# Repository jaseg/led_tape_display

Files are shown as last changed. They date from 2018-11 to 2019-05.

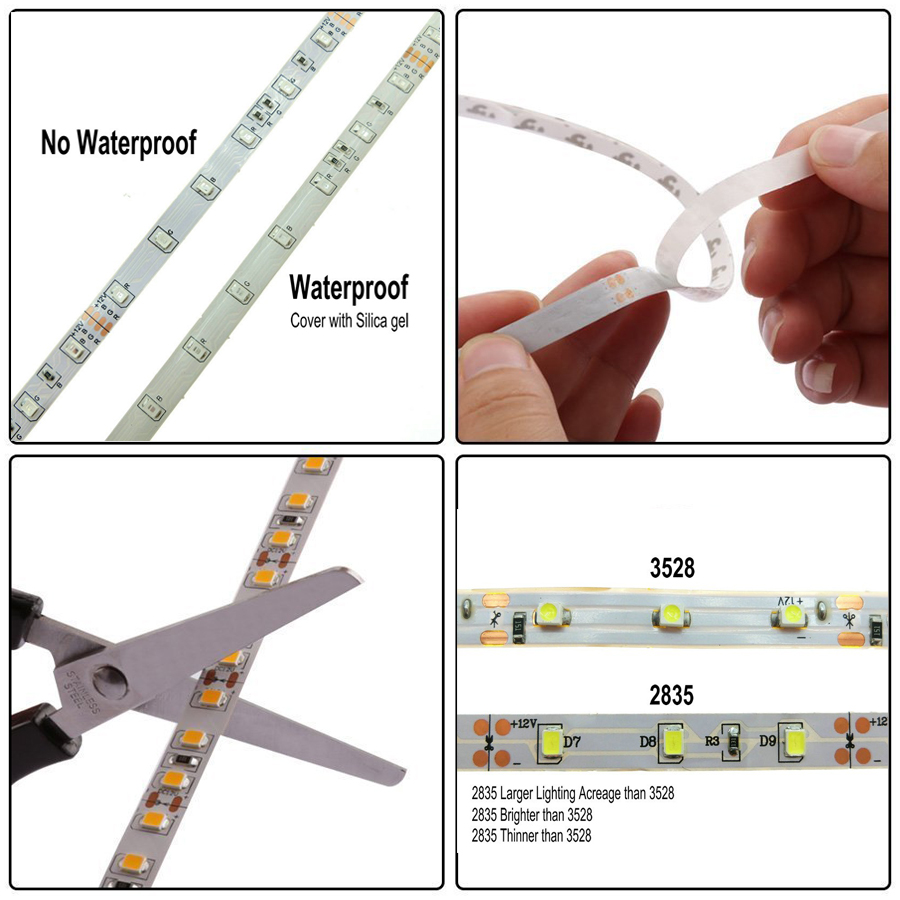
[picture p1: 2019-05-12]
driver/led_tape.png

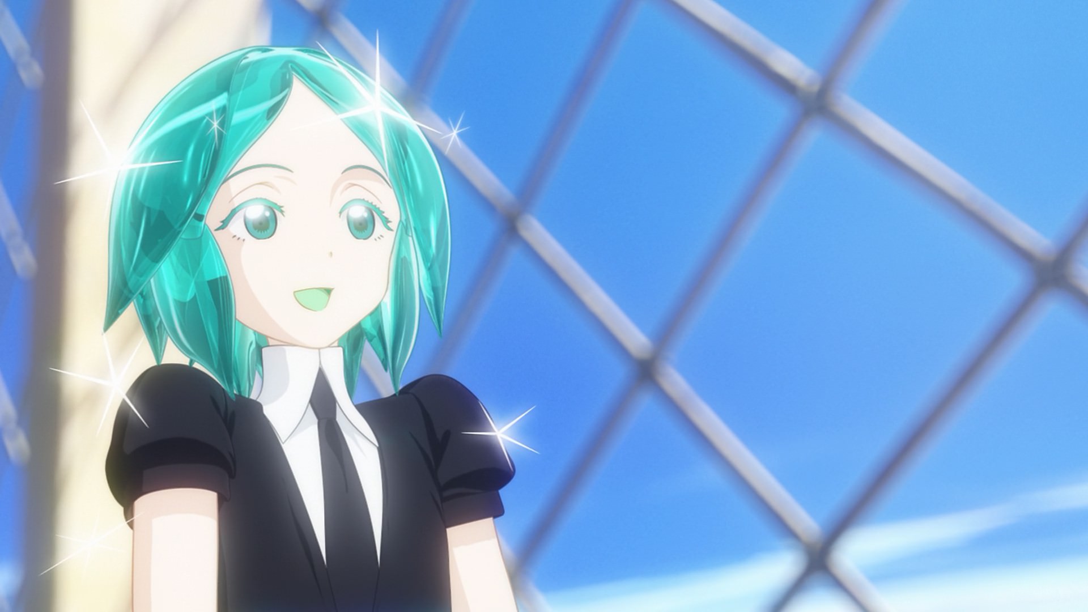
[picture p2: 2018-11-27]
center/phos.jpg

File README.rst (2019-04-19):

LED-tape based segment display
==============================

This is a work-in-progress repository containing hard- and software source files for an 8-segment LED display based on
cheap single-color LED tape. The display consists of one digit driver per display digit that receive power and
transceive data through a two-wire powerline bus. This bus can support 10-50 digits depending on the size of the display
(and thus current consumption). The bus is driven by a driver board that is in turn controlled through RS-485.

The hardware is mostly finalized and can be found in ``center`` (digit controller) and ``driver`` (bus driver). The
firmware is still WIP and can be found in ``center_fw`` (digit controller), ``driver_fw`` (bus driver) and
``common`` (common 8b10b implementation).

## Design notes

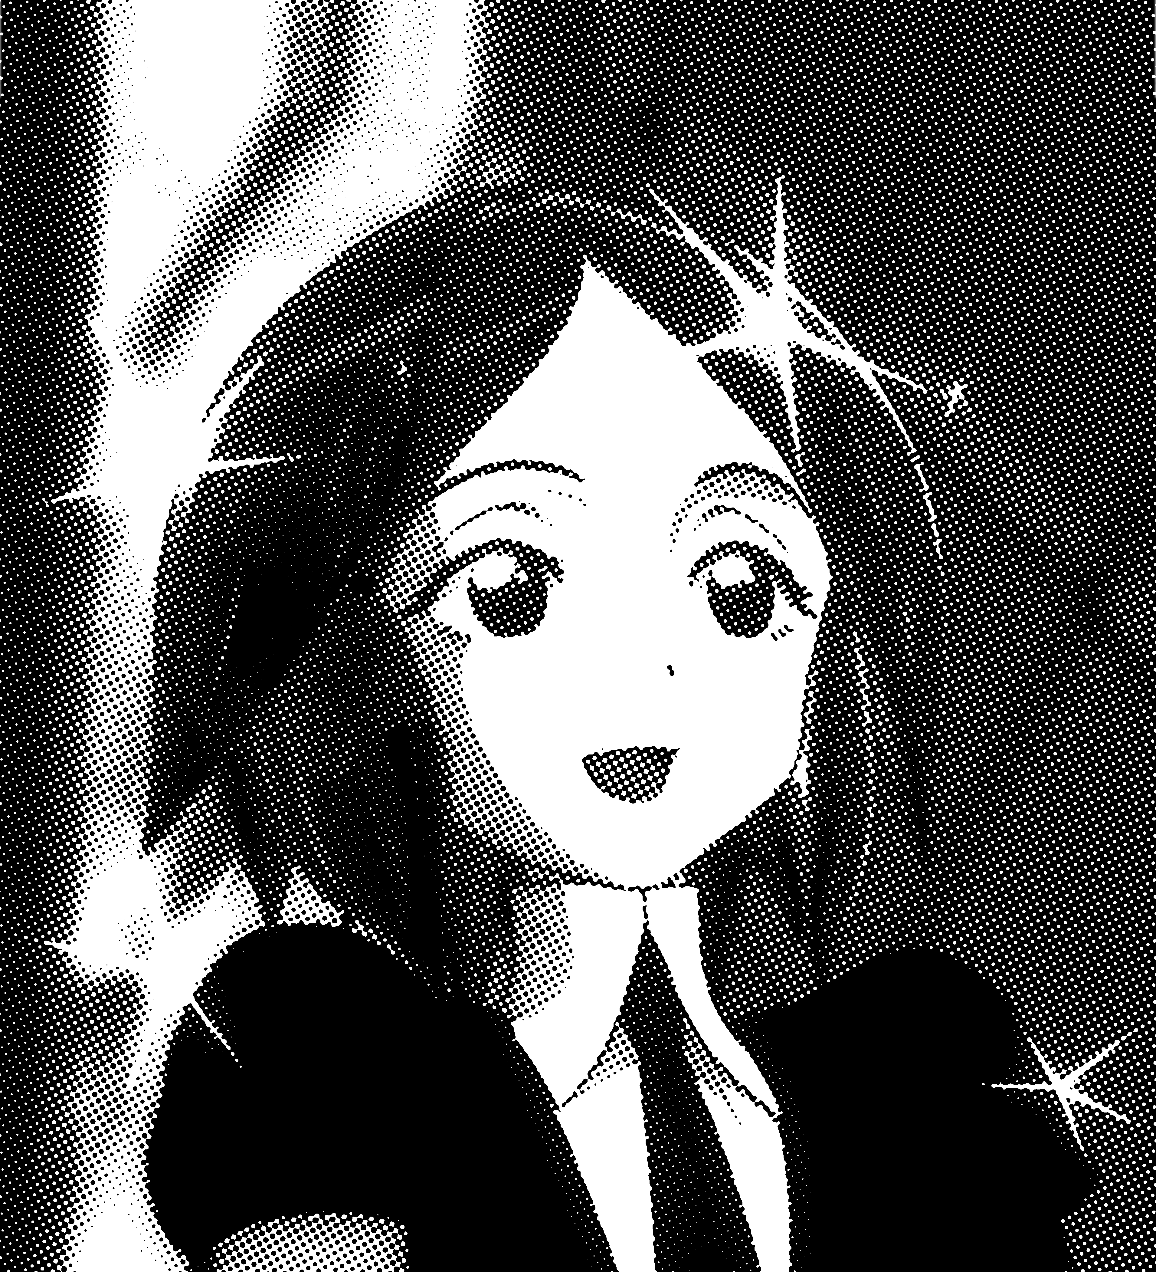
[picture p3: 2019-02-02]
center/tape_center_overlay.png

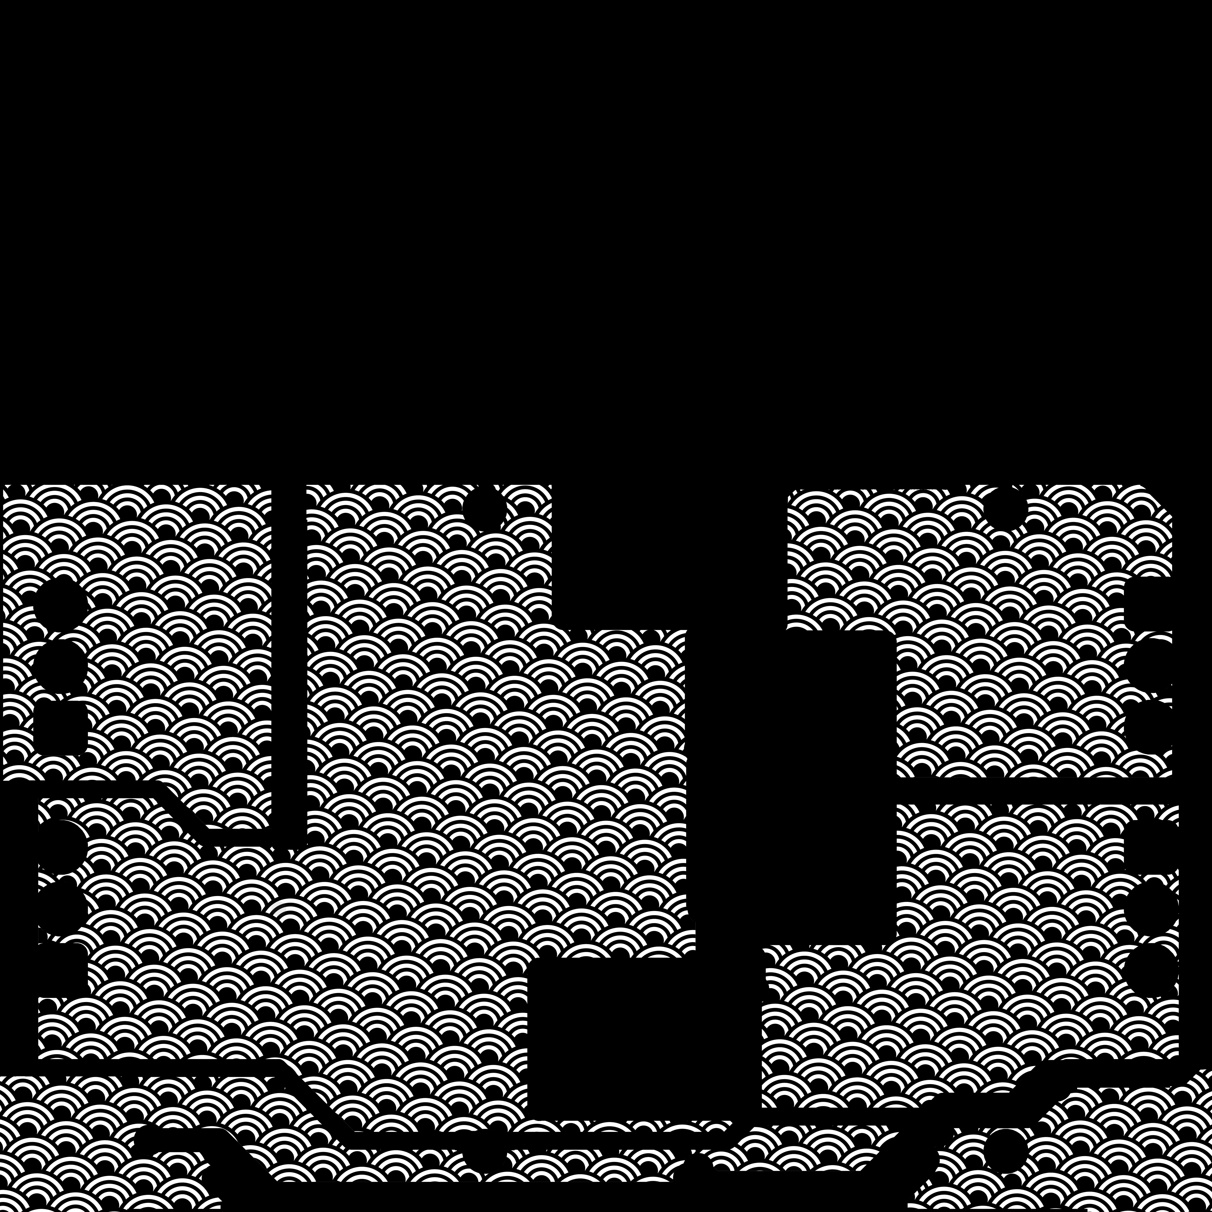
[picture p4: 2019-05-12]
driver/8seg_drv_bottom_mask_overlay_coarse.png

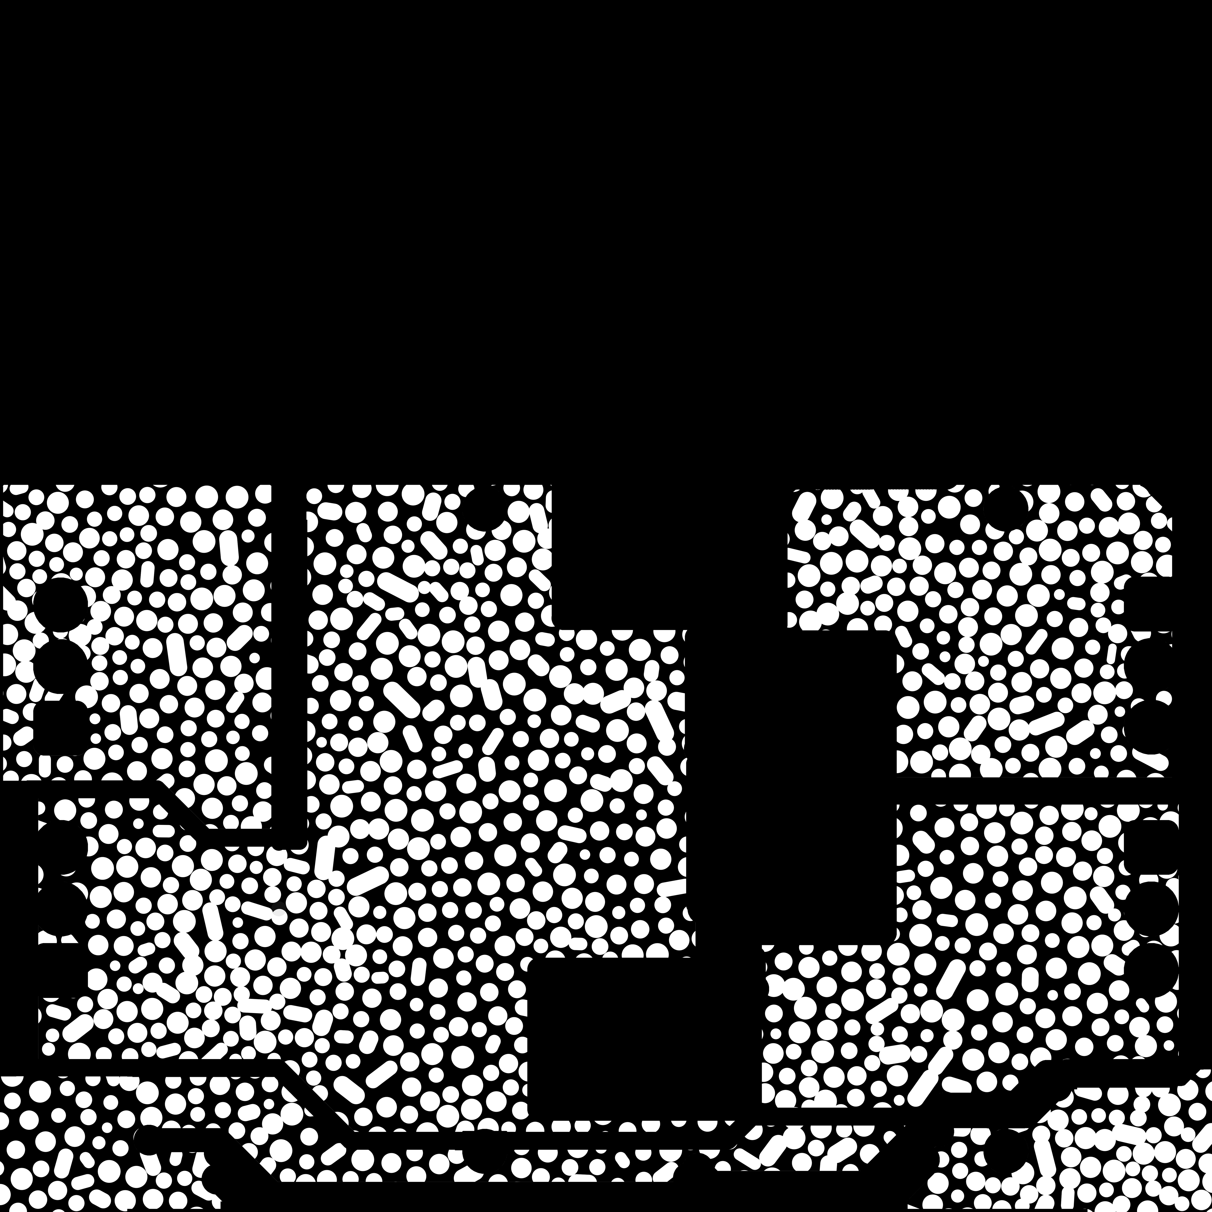
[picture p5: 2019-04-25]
driver/8seg_drv_bottom_mask_overlay.png

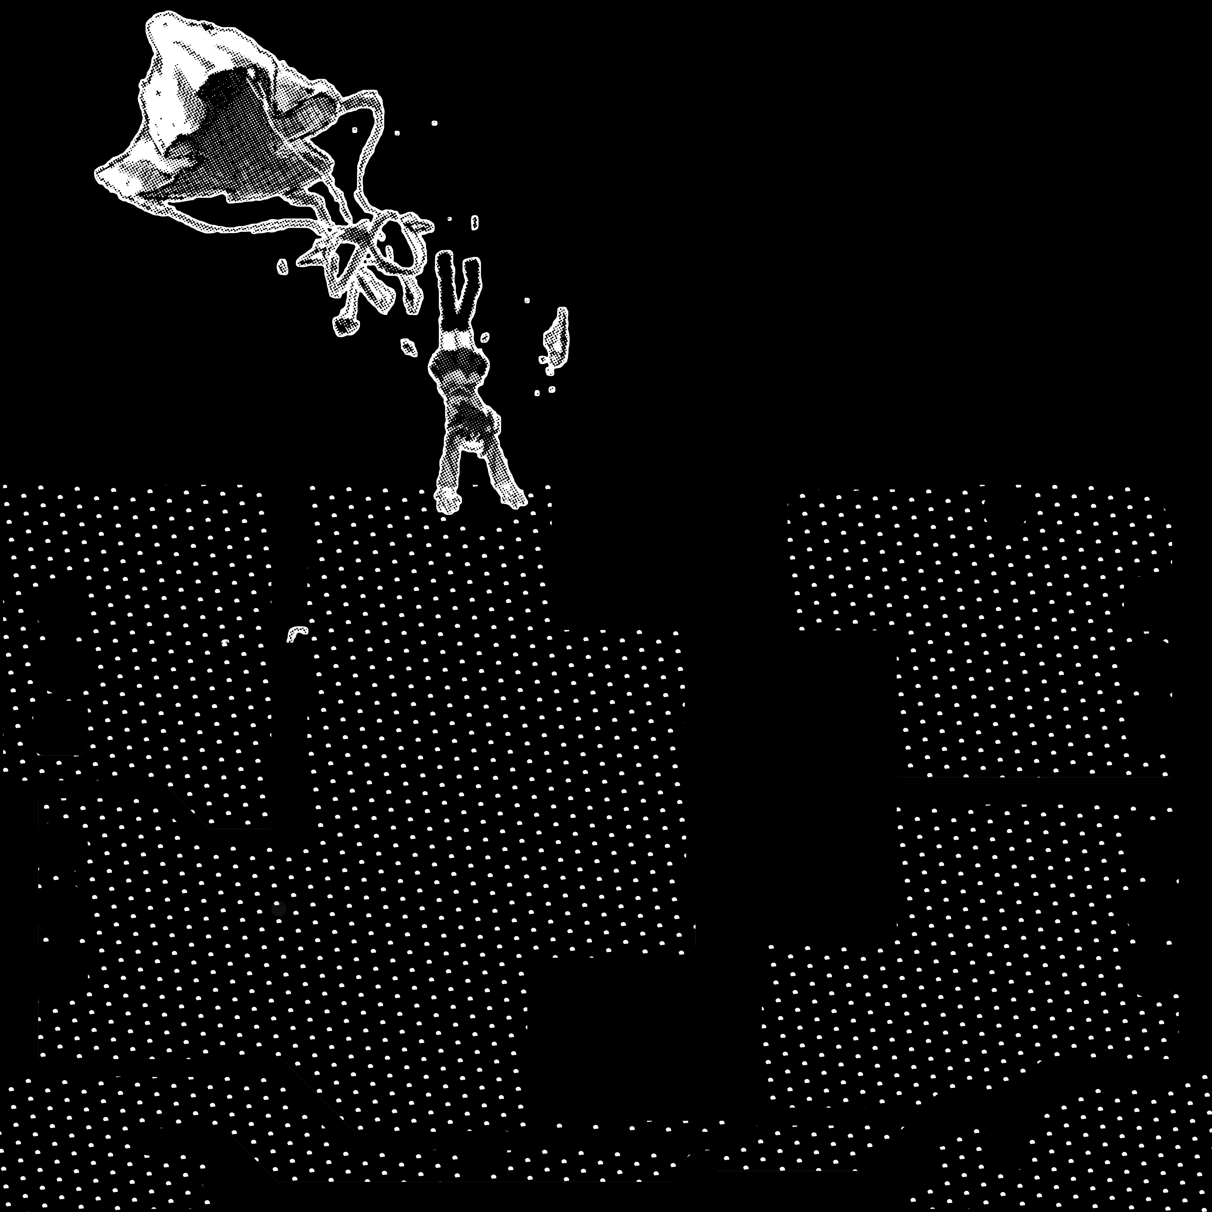
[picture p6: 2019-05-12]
driver/8seg_drv_bottom_silk_overlay.png

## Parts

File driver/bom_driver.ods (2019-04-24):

8seg Driver
Refs | # | Val | Pkg | Mfg | Source | P/N | JPY MOQ Price | USD MOQ Price | MOQ | URL
J1 | 1 | OUT_A OUT_B IN_VCC IN_GND | 3P P5.08 |  | LCSC |  |  | 1.46 | 5 | https://www.aliexpress.com/item/5PCS-PCB-Screw-Terminal-Blocks-Conenctor-2-54-3-5-3-81-5-0-5-08/32956034619.html
 | 1 | 1602 I2C LCD w/ backlight |  |  | Ali |  |  | 1.88 | 1 | https://www.aliexpress.com/item/1602-LCD-Module-Blue-Yellow-Green-Screen-with-IIC-I2C-16x2-LCD-Backlight-Module-LCD-1602/32891917063.html
R29 R30 R31 R32 R28 | 5 | 5mR 1W | 2512 |  | LCSC |  |  | 3.85 | 50 | https://www.aliexpress.com/item/50PCS-2512-SMD-Resistor-1-alloy-resistor-2W-0-005R-0-005-ohm-5mR-R005/32848255551.html
U1 | 1 | MT3608 | SOT23-6 |  | LCSC |  |  | 0.8 | 10 | https://www.aliexpress.com/item/10PCS-Special-chip-for-mobile-power-MT3608-B6286-SOT23-6-5V-1-2A/32838336209.html
U4 U5 | 2 | TC4427 | SOIC8 |  | LCSC |  |  | 2.76 | 10 | https://www.aliexpress.com/item/10PCS-TC4427ACOA-SOP-8-TC4427-SOP-TC4427AEOA-TC4427A-MOSFET-driver-new-original/32869458552.html
U7 | 1 | INA226 | MSOP10 P0.5 |  | LCSC |  |  | 2.2 | 1 | https://www.aliexpress.com/item/INA226AIDGS-INA226AIDGSR-INA226AIDGST-INA226/32822237180.html
U8 | 1 | MCP9804_SOIC | SOIC8 |  | LCSC |  | 282 |  | 1 | https://www.marutsu.co.jp/pc/i/27045774/
C10 | 1 | 22u | D5P2 |  | LCSC |  | 59 |  | 1 | https://www.marutsu.co.jp/pc/i/13867268/
J9 | 1 | SWD | Angled header 1x4 100mil |  | Stock |  | 48 |  | 10 | https://www.marutsu.co.jp/pc/i/59243/
L1 | 1 | 10u | NR50xx | Taiyo-Yuden | LCSC |  | 0.76 | 0.45 | 1 | https://www.marutsu.co.jp/GoodsDetail.jsp?q=%20NR5040T100M%20&salesGoodsCode=15561626&shopNo=3
Q1 Q2 Q3 Q4 | 4 | TPHR6503PL | SOP Advance |  | LCSC |  | 298 | 1.82 | 1 | https://www.digikey.com/product-detail/en/toshiba-semiconductor-and-storage/TPHR6503PLL1Q/TPHR6503PLL1QCT-ND/6099957
R1, R7 | 1 | 10R .5W | 1206 |  | LCSC |  | 5 |  | 1 | https://www.marutsu.co.jp/pc/i/857080/#
U6 | 1 | STM32F103C8Tx | LQFP48 P0.5 |  | Ali |  |  | 1.14 | 1 | https://www.aliexpress.com/item/CS32F103C8T6-Completely-replace-STM32F103C8T6-STM32F103-LQFP-48-In-Stock-ARM-based-32-bit-MCU-with-Flash/32952782064.html
U2 | 1 | AMS1117-5.0 | SOT223 |  | LCSC
U3 | 1 | AMS1117-3.3 | SOT223 |  | Stock
C15 | 1 | 100u | D10P5 |  | Stock
C16 C17 | 2 | 1u | 0603 |  | LCSC
C1 C18 C4 C9 | 4 | 10u | 0603 |  | Stock
C19 C2 C3 | 3 | 470u | D10P5 |  | Stock
C20 C22 | 2 | 12p | 0603 |  | Stock
C11 C12 C13 C14 C21 C23 C24 C29 C5 | 9 | 100n | 0603 |  | Stock
D1 | 1 | 2A schottky | SMB |  | Stock
U10 U9 | 2 | PC817 | DIP-4 |  | Stock
Y1 | 1 | 8MHz | 3225 |  | Stock
D2 D3 D4 D5 | 4 | cyan | 2835 |  | Stock
D6 D7 D8 D9 | 4 | pink | 2835 |  | Stock
J3 | 1 | UART_DEBUG | 1x4 100mil straight |  | Stock
J4 | 1 | USB_B_Micro |  |  | Stock
J5 | 1 | CH340E module | 1x6 straight high/female |  | Stock
J6 | 1 | LCD connector | XH2.54 4pin |  | Stock
R11 R12 R13 R14 R15 R16 R17 R18 | 8 | 150 | 0603 |  | Stock
R19 R20 R21 R22 | 4 | 0R | 0603 |  | Stock
R2 | 1 | 100k | 0603 |  | Stock
R23 R26 R27 R37 R38 | 5 | 1k5 | 0603 |  | Stock
R24 R25 | 2 | 22 | 0603 |  | Stock
R3 R8 | 2 | 47k | 0603 |  | Stock
R33 R35 | 2 | 390 | 0603 |  | Stock
R34 | 1 | 720 | 0603 |  | Stock
R39 | 1 | 680 | 0603 |  | Stock
R4 | 1 | 3k3 | 0603 |  | Stock
R10 R36 R5 R9 | 4 | 10k | 0603 |  | Stock
SW1 SW2 | 2 | SW_Push | 6mm switch |  | Stock

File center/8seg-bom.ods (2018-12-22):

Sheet: Sheet1
8seg
Number of devices: |  | 20
Description | Available? | Package | Mfg | MPN | Supplier | Supplier PN | Qty | MOQ | Unit | Price/MOQ | Price/ Unit | Price base | Price total | MOQ match | Price total MOQ | Excl | TempSum | MOQ delta cost | MOQ delta qty | URL
uC STM32 | stock | TSSOP-20 | ST | STM32F030F4P6 | Ali |  | 1 | 50 | Pcs | $20.900 | $0.418 | $0.418 | $8.360 | 50 | $20.900 |  | $20.900 | $12.540 | 30 | https://www.aliexpress.com/item/Free-shipping-50pcs-lots-STM32F030F4P6-STM32F030-MCU-ARM-16K-FLASH-20TSSOP-best-quality/32281734555.html
Voltage regulator 3.3V | stock | SOT-223 |  | AP1117-33 | Ali |  | 2 | 100 | Pcs | $1.770 | $0.018 | $0.035 | $0.708 | 100 | $1.770 |  | $1.770 | $1.062 | 60 | https://www.aliexpress.com/item/Free-Shipping-One-Lot-100pcs-AMS1117-3-3V-AMS1117-1117-3-3V-1A-Voltage-Regulator-LDO/2040294608.html
Schottky diode | ordered | SMB |  | SS510 | Ali |  | 4 | 100 | Pcs | $2.780 | $0.028 | $0.111 | $2.224 | 100 | $2.780 |  | $2.780 | $0.556 | 20 | https://www.aliexpress.com/item/100pcs-lot-Diode-SS510-SMB-SCHOTTKY-DIODE-5A-100V/32763626070.html
C 1000u 25V | ordered | D10/P5.0 |  |  | Ali |  | 1 | 50 | Pcs | $3.660 | $0.073 | $0.073 | $1.464 | 50 | $3.660 |  | $3.660 | $2.196 | 30 | https://www.aliexpress.com/item/CNIKESIN-50PCS-25V1000UF-new-genuine-high-quality-power-supply-line-super-electrolytic-capacitor-1000UF-25V-10X17mm/3281012004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
C 470uF 10V | ordered | D10/P5.0 |  |  | Ali |  | 1 | 30 | Pcs | $1.380 | $0.046 | $0.046 | $0.920 | 30 | $1.380 |  | $1.380 | $0.460 | 10 | https://www.aliexpress.com/item/25V-470UF-8-12-aluminum-electrolytic-capacitor-470uf-25v/32814887162.html
C 0603 10u/6.3V X7R | ordered | 0603 | Samsung | CL10A106MQ8NNNC | LCSC |  | 1 | 50 | Pcs |  | $0.014 | $0.014 | $0.272 | 50 | $0.680 |  | $0.680 | $0.408 | 30 | https://lcsc.com/product-detail/Multilayer-Ceramic-Capacitors-MLCC-SMD-SMT_SAMSUNG_CL10A106MQ8NNNC_10uF-106-20-6-3V_C1691.html
C 0603 10u/25V X7R | ordered | 0603 | Murata | GRM188R61E106MA73D | LCSC |  | 1 | 50 | Pcs |  | $0.118 | $0.118 | $0.000 | 50 | $5.875 | 1 | $0.000 | $0.000 | 30 | https://lcsc.com/product-detail/Multilayer-Ceramic-Capacitors-MLCC-SMD-SMT_MuRata_GRM188R61E106MA73D_10uF-106-20-25V_C91606.html
C 0603 100n | stock | 0603 | Huaxin | 0603B104M250 | LCSC |  | 2 | 50 | Pcs |  | $0.009 | $0.017 | $0.340 | 50 | $0.425 |  | $0.425 | $0.085 | 10 | https://lcsc.com/product-detail/Multilayer-Ceramic-Capacitors-MLCC-SMD-SMT_100nF-104-20-25V_C107569.html
R 10k 1% | stock | 0603 | Ralec | RTT031002FTP | LCSC |  | 4 | 100 | Pcs |  | $0.002 | $0.008 | $0.152 | 100 | $0.190 |  | $0.190 | $0.038 | 20 | https://lcsc.com/product-detail/Chip-Resistor-Surface-Mount_10KR-1002-1_C103199.html
R 3k3 1% | stock | 0603 | Ralec | RTT033302FTP | LCSC |  | 2 | 100 | Pcs |  | $0.005 | $0.010 | $0.200 | 100 | $0.500 |  | $0.500 | $0.300 | 60 | https://lcsc.com/product-detail/Chip-Resistor-Surface-Mount_33KR-3302-1_C103544.html
Schottky diode | ordered | MiniMELF | Semtech | LL60P-D4004 | LCSC |  | 2 | 100 | Pcs |  | $0.029 | $0.058 | $1.168 | 100 | $2.920 |  | $2.920 | $1.752 | 60 | https://lcsc.com/product-detail/Schottky-Barrier-Diodes-SBD_STLL60P_C51724.html
MOSFET P-ch | stock | SOT-23 | Various | AO3401 | Ali |  | 2 | 100 | Pcs | $1.770 | $0.018 | $0.040 | $0.796 | 100 | $1.990 |  | $1.990 | $1.194 | 60 | https://www.aliexpress.com/item/100pcs-lot-free-shipping-MOS-AO3401-AO3401A19T-SOT-23-100-new-Original-Quality-Assurance/2030993203.html
Zener diode 8.2V | ordered | MiniMELF |  |  | Ali |  | 2 | 200 | Pcs | $0.980 | $0.005 | $0.010 | $0.196 | 200 | $0.980 |  | $0.980 | $0.784 | 160 | https://www.aliexpress.com/item/1-2W-Zener-diode-ZMM-0-5W-2V0-2V2-2V4-2V7-3V0-3V3-3V6-3V9-4V3/32829966736.html
Crystal 8MHz | ordered | 3225 |  |  | Ali |  | 1 | 10 | Pcs | $1.470 | $0.147 | $0.147 | $0.000 | 20 | $2.940 | 1 | $0.000 | $0.000 | 0 | https://www.aliexpress.com/item/10pcs-3-2x2-5-3225-12-16-25-24-26-40-20-8-27-32MHZ-passive/32954531147.html
C 12p | ordered | 0603 | Huaxin | 0603N120G500CT | LCSC |  | 2 | 50 | Pcs |  | $0.010 | $0.020 | $0.404 | 50 | $0.505 |  | $0.505 | $0.101 | 10 | https://lcsc.com/product-detail/Multilayer-Ceramic-Capacitors-MLCC-SMD-SMT_Huaxin-S-T-0603N120G500CT_C302050.html
Male header 1*4P | ordered | P2.54 |  |  | LCSC |  | 1 | 20 | Pcs |  | $0.019 | $0.019 | $0.376 | 20 | $0.376 |  | $0.376 | $0.000 | 0 | https://lcsc.com/product-detail/Male-Header_2-54mm-1-4P-HeaderG-FRegular_C152150.html
MOSFET N-ch | stock | SOT-23 | Various | AO3400 | Ali |  | 3 | 100 | Pcs | $1.990 | $0.020 | $0.060 | $1.194 | 100 | $1.990 |  | $1.990 | $0.796 | 40 | https://www.aliexpress.com/item/Free-shipping-20pcs-SMD-mosfet-transistor-SOT-23-AO3400/32360580221.html
R 620 2W | ordered | 2512 | Ralec | RTT25621JTE | LCSC |  | 1 | 50 | Pcs |  | $0.014 | $0.014 | $0.288 | 50 | $0.720 |  | $0.720 | $0.432 | 30 | https://lcsc.com/product-detail/Chip-Resistor-Surface-Mount_620R-621-5_C159179.html
PCB 58*64mm center | ordered |  |  |  | JLCPCB |  | 1 | 50 | Pcs | $18.160 | $0.363 | $0.363 | $7.264 | 50 | $18.160 |  | $18.160 | $10.896 | 30
PCB 50*50mm corner | ordered |  |  |  | JLCPCB |  | 4 | 10 | Pcs | $2.000 | $0.200 | $0.800 | $16.000 | 80 | $16.000 |  | $16.000 | $0.000 | 0
LED tape pink | ordered |  |  |  | Ali |  | 8.6 | 5 | m | $1.820 | $0.364 | $3.130 | $62.608 | 175 | $63.700 |  | $63.700 | $1.092 | 3 | https://www.aliexpress.com/item/2835-LED-Strip-Light-DC12V-IP30-not-waterproof-IP65-waterproof-SMD-3528-LED-Diode-Flexible-Tape/32881123416.html
 |  |  |  |  |  |  |  |  |  |  | Total | $5.511 | $104.934 |  |  | Total | $139.626 | $34.692
Notes:

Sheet: center
U2 | STM32F030F4P6 | Housings_SSOP:TSSOP-20_4.4x6.5mm_Pitch0.65mm | http://www.st.com/st-web-ui/static/active/en/resource/technical/document/datasheet/DM00088500.pdf
U1 | AP1117-33 | TO_SOT_Packages_SMD:SOT-223-3Lead_TabPin2 | http://www.diodes.com/datasheets/AP1117.pdf
J1 | top left | footprints:led_tape_3528_2835 | ~
J2 | top right | footprints:led_tape_3528_2835 | ~
J3 | bottom right | footprints:led_tape_3528_2835 | ~
J4 | bottom left | footprints:led_tape_3528_2835 | ~
D1 | SS510 | Diodes_SMD:D_SMB_Handsoldering | ~
D3 | SS510 | Diodes_SMD:D_SMB_Handsoldering | ~
D2 | SS510 | Diodes_SMD:D_SMB_Handsoldering | ~
D4 | SS510 | Diodes_SMD:D_SMB_Handsoldering | ~
C1 | 1000uF | Capacitor_THT:CP_Radial_D10.0mm_P5.00mm | ~
C4 | 470uF | Capacitor_THT:CP_Radial_D10.0mm_P5.00mm | ~
C2 | 10u | Capacitors_SMD:C_0603_HandSoldering | ~
C3 | 100n | Capacitors_SMD:C_0603_HandSoldering | ~
C5 | 10u | Capacitors_SMD:C_0603_HandSoldering | ~
C6 | 100n | Capacitors_SMD:C_0603_HandSoldering | ~
R1 | 10k | Resistors_SMD:R_0603_HandSoldering | ~
R2 | 10k | Resistors_SMD:R_0603_HandSoldering | ~
R4 | 3k3 | Resistors_SMD:R_0603_HandSoldering | ~
R3 | 3k3 | Resistors_SMD:R_0603_HandSoldering | ~
D6 | D_Schottky | Diodes_SMD:D_MiniMELF_Handsoldering | ~
D5 | D_Schottky | Diodes_SMD:D_MiniMELF_Handsoldering | ~
R10 | 620 | Resistors_SMD:R_2512_HandSoldering | ~
R11 | 0 | Resistors_SMD:R_0603_HandSoldering | ~
C12 | 0 | Capacitors_SMD:C_0805 | ~
R12 | 0 | Resistors_SMD:R_0603_HandSoldering | ~
C13 | 0 | Capacitors_SMD:C_0805 | ~
R6 | 0 | Resistors_SMD:R_0603_HandSoldering | ~
C8 | 0 | Capacitors_SMD:C_0603_HandSoldering | ~
Q2 | AO3401 | TO_SOT_Packages_SMD:SOT-23 | https://www.infineon.com/dgdl/irlml6402pbf.pdf?fileId=5546d462533600a401535668d5c2263c
R7 | 10k | Resistors_SMD:R_0603_HandSoldering | ~
C7 | 0 | Capacitors_SMD:C_0603_HandSoldering | ~
D7 | 8V2 | Diodes_SMD:D_MiniMELF_Handsoldering | ~
R9 | 0 | Resistors_SMD:R_0603_HandSoldering | ~
Q5 | AO3401 | TO_SOT_Packages_SMD:SOT-23 | https://www.infineon.com/dgdl/irlml6402pbf.pdf?fileId=5546d462533600a401535668d5c2263c
R13 | 10k | Resistors_SMD:R_0603_HandSoldering | ~
C11 | 0 | Capacitors_SMD:C_0805 | ~
D8 | 8V2 | Diodes_SMD:D_MiniMELF_Handsoldering | ~
R14 | 0 | Resistors_SMD:R_0603_HandSoldering | ~
Y1 | 8MHz | Crystals:Crystal_SMD_3225-4pin_3.2x2.5mm | ~
C10 | 12p | Capacitors_SMD:C_0603_HandSoldering | ~
C9 | 12p | Capacitors_SMD:C_0603_HandSoldering | ~
R5 | 0 | Resistors_SMD:R_0603_HandSoldering | ~
R8 | 0 | Resistors_SMD:R_0603_HandSoldering | ~
J5 | SWD | Pin_Headers:Pin_Header_Straight_1x04_Pitch2.54mm | ~
TP1 | TestPoint | Measurement_Points:Measurement_Point_Square-SMD-Pad_Small | ~
TP2 | TestPoint | Measurement_Points:Measurement_Point_Square-SMD-Pad_Small | ~
TP3 | TestPoint | Measurement_Points:Measurement_Point_Square-SMD-Pad_Small | ~
TP4 | TestPoint | Measurement_Points:Measurement_Point_Square-SMD-Pad_Small | ~
Q1 | AO3400 | Package_TO_SOT_SMD:SOT-23 | http://www.farnell.com/datasheets/1835997.pdf
Q3 | AO3400 | Package_TO_SOT_SMD:SOT-23 | http://www.farnell.com/datasheets/1835997.pdf
Q4 | AO3400 | Package_TO_SOT_SMD:SOT-23 | http://www.farnell.com/datasheets/1835997.pdf

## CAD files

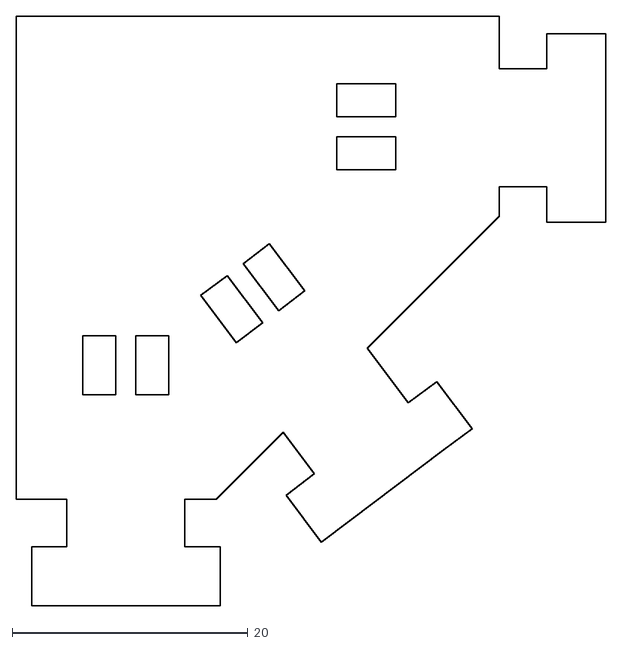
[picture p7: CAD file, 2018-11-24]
board_outline.dxf
50.0 x 50.0

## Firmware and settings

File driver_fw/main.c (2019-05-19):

/* 8seg LED display driver firmware
 * Copyright (C) 2018 Sebastian Götte <code@jaseg.net>
 * 
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
 * You should have received a copy of the GNU General Public License
 * along with this program.  If not, see <http://www.gnu.org/licenses/>.
 */


#include "global.h"
#include "serial.h"
#include "i2c.h"
#include "lcd1602.h"
#include "mcp9801.h"
#include "ina226.h"

#include "mini-printf.h"

#include <8b10b.h>

/* Part number: STM32F030F4C6 */

volatile unsigned int comm_led_ctr, err_led_ctr;
volatile unsigned int sys_time_tick = 0;
volatile unsigned int sys_time_ms;
volatile unsigned int sys_time_s;
volatile unsigned int sys_flag_1Hz;
unsigned int frame_duration_us;
volatile uint8_t global_brightness; /* FIXME implement sending */

void trigger_error_led() {
    err_led_ctr = STATUS_LED_DURATION_MS/TICK_MS;
}

void trigger_comm_led() {
    comm_led_ctr = STATUS_LED_DURATION_MS/TICK_MS;
}

static volatile struct {
    int current_symbol;
    struct state_8b10b_enc st;
} txstate;

#define NO_SYMBOL (DECODER_RETURN_CODE_LAST + 1)

uint8_t random() {
    static uint8_t x, a, b, c;
    x++; //x is incremented every round and is not affected by any other variable
    a = (a ^ c ^ x); //note the mix of addition and XOR
    b = (b + a); //And the use of very few instructions
    c = ((c + ((b >> 1) ^ a))); // the AES S-Box Operation ensures an even distributon of entropy
    return c;
}

enum STATUS_LEDS {
    STATUS_LED_COMMUNICATION = 1,
    STATUS_LED_ERROR = 2,
    STATUS_LED_LOAD = 4,
    STATUS_LED_OPERATION = 8,
    STATUS_LED_J5_GREEN = 16,
    STATUS_LED_J5_YELLOW = 32,
    STATUS_LED_J4_GREEN = 64,
    STATUS_LED_J4_YELLOW = 128
};

static void set_status_leds(uint8_t val) {
    /* Reset strobe. Will be set in systick handler */
    GPIOA->BRR = 1<<4;
    /* Workaround for *nasty* hardware behavior: If SPI data width is configured as 8 bit but DR is written as 16
     * bit, SPI actually sends 16 clock cycles. Thus, we have to make sure the compiler emits a 8-bit write here.
     * Thanks, TI! */
    *((volatile uint8_t *)&(SPI1->DR)) = val ^ 0x0f; /* Invert LEDs connected to VCC instead of GND */
}


int main(void) {
    /* Startup code */
    RCC->CR |= RCC_CR_HSEON;
    while (!(RCC->CR&RCC_CR_HSERDY));
    RCC->CFGR &= ~RCC_CFGR_PLLMUL_Msk & ~RCC_CFGR_SW_Msk & ~RCC_CFGR_PPRE_Msk & ~RCC_CFGR_HPRE_Msk;
    RCC->CFGR |= ((6-2)<<RCC_CFGR_PLLMUL_Pos) | RCC_CFGR_PLLSRC_HSE_PREDIV; /* PLL x6 -> 48.0MHz */
    RCC->CR |= RCC_CR_PLLON;
    while (!(RCC->CR&RCC_CR_PLLRDY));
    RCC->CFGR |= (2<<RCC_CFGR_SW_Pos);
    RCC->AHBENR  |= RCC_AHBENR_DMAEN | RCC_AHBENR_GPIOAEN | RCC_AHBENR_GPIOBEN | RCC_AHBENR_FLITFEN;
    RCC->APB1ENR |= RCC_APB1ENR_TIM3EN | RCC_APB1ENR_PWREN | RCC_APB1ENR_I2C1EN;
    RCC->APB2ENR |= RCC_APB2ENR_SYSCFGEN | RCC_APB2ENR_ADCEN| RCC_APB2ENR_DBGMCUEN | RCC_APB2ENR_USART1EN | RCC_APB2ENR_SPI1EN;

    SystemCoreClockUpdate();
    SysTick_Config(SystemCoreClock/(1000/TICK_MS)); /* 10ms interval */
    NVIC_EnableIRQ(SysTick_IRQn);
    NVIC_SetPriority(SysTick_IRQn, 3<<5);

    /* GPIO setup
     *
     * Note: since we have quite a bunch of pin constraints we can't actually use complementary outputs for the
     * complementary MOSFET driver control signals (CTRL_A & CTRL_B). Instead, we use two totally separate output
     * channels (1 & 4) and emulate the dead-time generator in software.
     */
    GPIOA->MODER |=
          (3<<GPIO_MODER_MODER0_Pos)  /* PA0  - Vboot to ADC */
        | (2<<GPIO_MODER_MODER1_Pos)  /* PA1  - RS485 DE */
        | (2<<GPIO_MODER_MODER2_Pos)  /* PA2  - RS485 TX */
        | (2<<GPIO_MODER_MODER3_Pos)  /* PA3  - RS485 RX */
        | (1<<GPIO_MODER_MODER4_Pos)  /* PA4  - Strobe/Vin to ADC. CAUTION: This pin is dual-use  */
        | (2<<GPIO_MODER_MODER5_Pos)  /* PA5  - SCK */
        | (2<<GPIO_MODER_MODER6_Pos)  /* PA6  - CTRL_A  to TIM 3 ch 1 */
        | (2<<GPIO_MODER_MODER7_Pos)  /* PA7  - MOSI */
        | (2<<GPIO_MODER_MODER9_Pos)  /* PA9  - SCL */
        | (2<<GPIO_MODER_MODER10_Pos);/* PA10 - SDA */

    GPIOA->AFR[0] =
          (1<<GPIO_AFRL_AFSEL1_Pos)  /* PA1 */
        | (1<<GPIO_AFRL_AFSEL2_Pos)  /* PA2 */
        | (1<<GPIO_AFRL_AFSEL3_Pos)  /* PA3 */
        | (1<<GPIO_AFRL_AFSEL6_Pos); /* PA6 */
    GPIOA->AFR[1] =
          (4<<GPIO_AFRH_AFSEL9_Pos)  /* PA9 */
        | (4<<GPIO_AFRH_AFSEL10_Pos);/* PA10 */

    GPIOA->ODR = 0; /* Set PA4 ODR to 0 */

    GPIOA->OTYPER |=
          GPIO_OTYPER_OT_1
        | GPIO_OTYPER_OT_2;

    // FIXME lag 37.3us @ 720 Ohm / 16.0us @ 360 Ohm / 2.8us @ 88 Ohm
    GPIOA->OSPEEDR |=
          (3<<GPIO_OSPEEDR_OSPEEDR1_Pos)
        | (3<<GPIO_OSPEEDR_OSPEEDR2_Pos);

    GPIOB->MODER |=
          (2<<GPIO_MODER_MODER1_Pos); /* PB1  - CTRL_B to TIM 3 ch 4 */

    GPIOB->AFR[0] = (1<<GPIO_AFRL_AFSEL1_Pos); /* PB1 */

    serial_init();
    /* FIXME ADC config */

    /* SPI config. SPI1 is used to control the shift register controlling the eight status LEDs. */
    SPI1->CR2 = (7<<SPI_CR2_DS_Pos);

    /* Baud rate PCLK/128 -> 375.0kHz */
    SPI1->CR1 =
          SPI_CR1_SSM
        | SPI_CR1_SSI
        | (6<<SPI_CR1_BR_Pos)
        | SPI_CR1_MSTR;
    SPI1->CR1 |= SPI_CR1_SPE;

    /* I2C for LCD, temp sensor, current sensor */
    i2c_config_filters(I2C1, I2C_AF_ENABLE, 0);
    i2c_config_timing(I2C1, 0x2000090e); /* Magic value for 100kHz I2C @ 48MHz CLK. Fell out of STMCubeMX. I love
                                           downloading 120MB of software to download another 100MB of software, only
                                           this time over unsecured HTTP, to generate 3.5 bytes of configuration values
                                           using a Java(TM) GUI. */
    i2c_enable(I2C1);
    lcd1602_init();
    ina226_init(); /* Current/voltage monitor */
    mcp9801_init(); /* MOSFET temperature. Placed between middle two low-side MOSFETs. */

    /* TIM3 is used to generate the MOSFET driver control signals */
    /* TIM3 running off 48MHz APB1 clk, T=20.833ns */
    TIM3->CR1 = 0; /* Disable ARR preload (double-buffering) */
    TIM3->PSC = 48-1; /* Prescaler 48 -> f=1MHz/T=1us */
    TIM3->DIER = TIM_DIER_UIE; /* Enable update (overflow) interrupt */

    /* Set both CCRs to 0xffff to ensure both bridge halves are turned off after we enable the timer. If we don't do
     * this, we will cause a very low-ohm short circuit that at best will trigger our power supply's short-circuit or
     * over-current protection right after power-on but at worst will detonate the mosfets.  */
    TIM3->CCR1 = 0xffff;
    TIM3->CCR4 = 0xffff;
    /* Configure output compare unit 1 to PWM mode 1, enable CCR1 preload */
    TIM3->CCMR1 = 6<<TIM_CCMR1_OC1M_Pos | TIM_CCMR1_OC1PE;
    /* Configure output compare unit 4 to PWM mode 1, enable CCR4 preload */
    TIM3->CCMR2 = 6<<TIM_CCMR2_OC4M_Pos | TIM_CCMR2_OC4PE;
    /* Confiugre CH1 to complementary outputs */
    TIM3->CCER = TIM_CCER_CC1E | TIM_CCER_CC1P | TIM_CCER_CC4E | TIM_CCER_CC4P;
    /* Enable MOE on next update event, i.e. on initial timer load. */
    TIM3->BDTR = TIM_BDTR_MOE;
    /* Enable timer */
    TIM3->CR1 |= TIM_CR1_CEN;
    /* Set f=1.25kHz/T=0.8ms */
    TIM3->ARR = 800-1;

    /* Initialize AC protocol state machine in TIM3 ISR with the AC protocol comma */
    xfr_8b10b_encode_reset(&txstate.st);
    txstate.current_symbol = xfr_8b10b_encode(&txstate.st, K28_1) | 1<<10;
    /* The timer is still stopped. Start it by manually triggering an update event. */
    TIM3->EGR |= TIM_EGR_UG;

    NVIC_EnableIRQ(TIM3_IRQn);
    NVIC_SetPriority(TIM3_IRQn, 2<<4);

    lcd_write_str(0, 0, "8seg driver");
    lcd_write_str(0, 1, "initialized \xbc");
    while (42) {
        if (sys_flag_1Hz) { /* Update display every second */
            sys_flag_1Hz = 0; 

            char buf[17];
            int temp = mcp9801_read_mdegC();
            int deg = temp/1000;
            int frac = (temp%1000)/100;
            mini_snprintf(buf, sizeof(buf), "Temp: %d.%01d\xdf""C" LCD_FILL, deg, frac);
            lcd_write_str(0, 0, buf);
            mini_snprintf(buf, sizeof(buf), "I=%dmA U=%dmV" LCD_FILL, ina226_read_i()*INA226_I_LSB_uA/1000, ina226_read_v()*INA226_VB_LSB_uV/1000);
            lcd_write_str(0, 1, buf);
        }
    }
}

static int flipbits10(int in) {
    return
        (in&0x200)>>9 |
        (in&0x100)>>7 |
        (in&0x080)>>5 |
        (in&0x040)>>3 |
        (in&0x020)>>1 |
        (in&0x010)<<1 |
        (in&0x008)<<3 |
        (in&0x004)<<5 |
        (in&0x002)<<7 |
        (in&0x001)<<9;

}

#define BACKCHANNEL_INTERVAL 10

void TIM3_IRQHandler() {
    static int txpos = -1;
    static unsigned int tx_start_tick = 0;
    static uint8_t txbuf[2] = {0x04, 0x05};
    static int backchannel_counter = 0;

    TIM3->SR &= ~TIM_SR_UIF;
    int sym = txstate.current_symbol;
    int bit = sym&1;
    sym >>= 1;
    if (sym == 1) { /* last bit shifted out */

        /* Insert the backchannel sync control symbol K.28.2 once every BACKCHANNEL_INTERVAL symbols independent from AC
         * forward channel protocol framing. The backchannel sync control symbol is different from the AC protocol comma
         * K.28.1. The backchannel sync control symbol is not a comma, so the 8b10b receiver cannot lock on it. The only
         * practical implication of this is that after powerup or other loss of sync, the receiver will only lock on the
         * backchannel sync once the first AC forward-channel protocol frame has been begun. Since all backchannel comm
         * is triggered by the driver anyway this should not be noticeable in practice.
         */
        backchannel_counter++;
        if (backchannel_counter == BACKCHANNEL_INTERVAL) {
            backchannel_counter = 0;
            sym = xfr_8b10b_encode(&txstate.st, -K28_2); /* TODO factor out backchannel comma into constant */

        } else {

            if (txpos == -1)
                sym = xfr_8b10b_encode(&txstate.st, -K28_1); /* TODO factor out comma into constant */
            else
                sym = xfr_8b10b_encode(&txstate.st, txbuf[txpos]);

            txpos++;
            if (txpos >= sizeof(txbuf)/sizeof(txbuf[0])) {
                frame_duration_us = (sys_time_tick - tx_start_tick) * 10 * 1000;
                tx_start_tick = sys_time_tick;
                txpos = -1;
            }
        }

        /* Append one '1' bit as an end-of-symbol marker for this state machine. This bit is not actually transmitted. */
        sym = flipbits10(sym) | 1<<10;
    }
    txstate.current_symbol = sym;

    /* FIXME factor out into header, or even make configurable */
#define DEAD_TIME 100
    /* Set both CCRs to values for opposing polarities. The dead time is always inserted at the beginning of the timer
     * cycle due to the way the capture/compare unit PWM machinery works. By setting the CCR to 0xffff we make sure the
     * output is never turned on, since 0xffff is larger than the ARR/counter top value.
     */
    TIM3->CCR1 = bit ? 0xffff : DEAD_TIME;
    TIM3->CCR4 = bit ? DEAD_TIME : 0xffff;
}

void NMI_Handler(void) {
}

void HardFault_Handler(void) __attribute__((naked));
void HardFault_Handler() {
    asm volatile ("bkpt");
}

void SVC_Handler(void) {
}


void PendSV_Handler(void) {
}

void SysTick_Handler(void) {
    sys_time_tick++;
    sys_time_ms += TICK_MS;
    if (sys_time_ms++ == 1000) {
        sys_time_ms = 0;
        sys_time_s++;
        sys_flag_1Hz = 1;
    }

    /* This is a hack. We could use the SPI interrupt here if that didn't fire at the start instead of end of transmission.... -.- */
    if (sys_time_tick&1) {
        uint8_t val = (sys_time_ms >= 300) ? STATUS_LED_OPERATION : 0;

        if (comm_led_ctr) {
            comm_led_ctr--;
            val |= STATUS_LED_COMMUNICATION;
        }

        if (err_led_ctr) {
            err_led_ctr--;
            val |= STATUS_LED_ERROR;
        }

        set_status_leds(val);
    } else {
        /* Reset strobe for the status LED shift register. Reset in set_status_leds. */
        GPIOA->BSRR = 1<<4;
    }
}

void _init(void) {
}

void BusFault_Handler(void) __attribute__((naked));
void BusFault_Handler() {
    asm volatile ("bkpt");
}

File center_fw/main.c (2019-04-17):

/* Megumin LED display firmware
 * Copyright (C) 2018 Sebastian Götte <code@jaseg.net>
 * 
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
 * You should have received a copy of the GNU General Public License
 * along with this program.  If not, see <http://www.gnu.org/licenses/>.
 */

#include "global.h"

#include "adc.h"
#include "8seg_protocol.h"
#include "transmit.h"

volatile unsigned int sys_time = 0;
volatile unsigned int sys_time_seconds = 0;
uint16_t jitter_meas_avg_ns = 0;

void TIM1_BRK_UP_TRG_COM_Handler() {
    TIM1->SR &= ~TIM_SR_UIF_Msk;
}

void set_drv_gpios(uint8_t val) {
    int a=!!(val&1), b=!!(val&2), c=!!(val&4), d=!!(val&8);
    GPIOA->BSRR = ((!a<<3 | !b<<7 | c<<6 | d<<4)<<16) | (a<<3 | b<<7 | !c<<6 | !d<<4);
}

uint8_t out_state = 0x01;
void set_outputs(uint8_t val[8]) {
    /* TODO implement BCM for digital brightness control */
    int x = 0;
    for (int i=0; i<8; i++)
        if (val[i] > 127)
            x |= 1<<i;
    out_state = x;
}

void set_outputs_binary(int mask, int global_brightness) {
    uint8_t val[8];
    for (int i=0; i<8; i++)
        val[i] = (mask & (1<<i)) ? global_brightness : 0;
    set_outputs(val);
}

void set_load(bool load) {
    GPIOA->BSRR = (1<<2) << (load ? 0 : 16);
}

void blank(void) {
    set_drv_gpios(0);
}

volatile int bit; /* FIXME */
void unblank_low(void) {
    if (backchannel_frame) { /* Set from protocol.c */
        if (tx_next_bit() == 1)
            set_load(1);
        else /* 0; but also TX_IDLE */
            set_load(0);

    } else {
        if (bit)
            set_drv_gpios(out_state & 0xf);
        else
            set_drv_gpios(out_state >> 4);
    }
}

void TIM3_IRQHandler(void) {
    GPIOA->BSRR = 1<<10; /* debug */
    if (TIM3->SR & TIM_SR_UIF)
        unblank_low();
    else
        blank();

    TIM3->SR = 0;
    GPIOA->BRR = 1<<10; /* debug */
}

int main(void) {
    RCC->CR |= RCC_CR_HSEON;
    while (!(RCC->CR&RCC_CR_HSERDY));
    RCC->CFGR &= ~RCC_CFGR_PLLMUL_Msk & ~RCC_CFGR_SW_Msk & ~RCC_CFGR_PPRE_Msk & ~RCC_CFGR_HPRE_Msk;
    RCC->CFGR |= ((6-2)<<RCC_CFGR_PLLMUL_Pos) | RCC_CFGR_PLLSRC_HSE_PREDIV; /* PLL x6 -> 48.0MHz */
    RCC->CR |= RCC_CR_PLLON;
    while (!(RCC->CR&RCC_CR_PLLRDY));
    RCC->CFGR |= (2<<RCC_CFGR_SW_Pos);
    SystemCoreClockUpdate();
    //SysTick_Config(SystemCoreClock/1000); /* 1ms interval */

    /* Turn on lots of neat things */
    RCC->AHBENR  |= RCC_AHBENR_DMAEN | RCC_AHBENR_GPIOAEN | RCC_AHBENR_FLITFEN;
    RCC->APB2ENR |= RCC_APB2ENR_SYSCFGEN | RCC_APB2ENR_ADCEN| RCC_APB2ENR_DBGMCUEN | RCC_APB2ENR_TIM1EN | RCC_APB2ENR_TIM1EN;;
    RCC->APB1ENR |= RCC_APB1ENR_TIM3EN;

    /* TIM3 foo */
    TIM3->CCMR2 = (6<<TIM_CCMR2_OC4M_Pos); /* PWM Mode 1 to get a clean trigger signal */
    TIM3->CCER  = TIM_CCER_CC4E; /* Enable capture/compare unit 4 connected to ADC */

    TIM3->PSC   =  48-1; /* 48MHz -> 1MHz */
    TIM3->CCR4  = 170-1; /* CC4 is ADC trigger, fire 30us before end of cycle. */
    TIM3->ARR   = 200-1; /* 1MHz -> 5kHz */

    TIM3->DIER |= TIM_DIER_UIE | TIM_DIER_CC4IE;

    TIM3->CR1  |= TIM_CR1_CEN;
    NVIC_EnableIRQ(TIM3_IRQn);
    NVIC_SetPriority(TIM3_IRQn, 3<<5);

    GPIOA->MODER |=
          (0<<GPIO_MODER_MODER0_Pos)  /* PA0  - Vmeas_A to ADC */
        | (0<<GPIO_MODER_MODER1_Pos)  /* PA1  - Vmeas_B to ADC */
        | (1<<GPIO_MODER_MODER2_Pos)  /* PA2  - LOAD */
        | (1<<GPIO_MODER_MODER3_Pos)  /* PA3  - CH0 */
        | (1<<GPIO_MODER_MODER4_Pos)  /* PA4  - CH3 */
        | (1<<GPIO_MODER_MODER5_Pos)  /* PA5  - TP1 */
        | (1<<GPIO_MODER_MODER6_Pos)  /* PA6  - CH2 */
        | (1<<GPIO_MODER_MODER7_Pos)  /* PA7  - CH1 */
        | (1<<GPIO_MODER_MODER9_Pos)  /* PA9  - TP2 */
        | (1<<GPIO_MODER_MODER10_Pos);/* PA10 - TP3 */

    /* Set shift register IO GPIO output speed */
    GPIOA->OSPEEDR |=
          (2<<GPIO_OSPEEDR_OSPEEDR2_Pos)   /* LOAD */
        | (2<<GPIO_OSPEEDR_OSPEEDR3_Pos)   /* CH0 */
        | (2<<GPIO_OSPEEDR_OSPEEDR4_Pos)   /* CH3   */
        | (2<<GPIO_OSPEEDR_OSPEEDR6_Pos)   /* CH2 */
        | (2<<GPIO_OSPEEDR_OSPEEDR7_Pos);  /* CH1 */

    set_drv_gpios(0);

    protocol_init();

    uint32_t jitter_meas_sum = 0, jitter_meas_cnt = 0;
    while (42) {
        int new = GPIOA->IDR & (1<<0); /* Sample current polarity */
        if (new != bit) { /* Zero-crossing detected */
            bit = new;

            /* Store old counter value for jitter measurement. Let it overflow to handle negative offsets. */
            int16_t cnt = (int16_t)TIM3->CNT;
            /* Re-initialize the counter to align it with the signal edge */
            TIM3->EGR  |= TIM_EGR_UG;
            /* Unblank since the update interrupt will not fire this time */
            unblank_low();

            /* Don't handle overflow of _sum here since this value is only for monitoring anyway */
            jitter_meas_sum += (cnt >= 0) ? cnt : -cnt;
            if (++jitter_meas_cnt == 4000) { /* One measurement roughly every 800ms */
                /* Divide aggregate over 4000 us-resolution measurements by 4 -> ns-resolution average */
                uint32_t divided = jitter_meas_sum>>2;
                jitter_meas_avg_ns = (divided < UINT16_MAX) ? divided : UINT16_MAX;
            }
        }
        /* idle */
    }
}

void NMI_Handler(void) {
    asm volatile ("bkpt");
}

void HardFault_Handler(void) __attribute__((naked));
void HardFault_Handler() {
    asm volatile ("bkpt");
}

void SVC_Handler(void) {
    asm volatile ("bkpt");
}


void PendSV_Handler(void) {
    asm volatile ("bkpt");
}

void SysTick_Handler(void) {
    static int n = 0;
    sys_time++;
    if (n++ == 1000) {
        n = 0;
        sys_time_seconds++;
    }
}

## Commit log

2018-11-25 center: initial schematic
    [center.kicad_pcb, center.sch]
2018-11-26 PCB designs R01 finished (not reviewed yet)
    [center.sch, circle_template.dxf, corner.kicad_pcb]
2018-11-26 center: improve silk
    [center.kicad_pcb]
2018-11-27 Fix AO3400 pinout
    [center-B.Cu.gbr, center-B.Mask.gbr, center-B.Paste.gbr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]
2018-11-27 Add prettified gerber output
    [center-B.Cu.gbr, center-B.Mask.gbr, center-B.Paste.gbr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]
2018-11-27 Add corner gerber exports
    [corner-B.Cu.gbr, corner-B.Mask.gbr, corner-B.Paste.gbr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]
2018-11-27 center: Add BOM
    [8seg-bom.ods, center.kicad_pcb]
2018-12-20 8b10b encoder and decoder working
    Tested on all 24-bit inputs after sync and on ~500M of random input
    with and without intermediate sync
2018-12-22 First AC/mux test working
    [8seg-bom.ods, center.kicad_pcb]
2018-12-23 ADC working
2018-12-24 Make center ADC work in "scope mode"
2018-12-24 Add untested ADC mode switching code
2018-12-24 Pimp ADC measurements with voltage means
2019-01-09 Fix up scope mode
    [adc.c, main.c]
2019-01-12 Basic timer-based blanking working
2019-01-15 Add initial driver schematic draft
    [driver.kicad_pcb, driver.sch]
2019-01-15 Fix double edge issue with driver
    [main.c]
2019-01-15 Driver schematic progress
    [driver.sch]
2019-01-17 driver: Initial layout
    [driver.kicad_pcb, driver.sch]
2019-01-17 driver: Continue layout
    [driver.kicad_pcb, driver.sch]
2019-01-17 driver: Initial layout almost done
    [driver.kicad_pcb, driver.sch]
2019-01-18 driver: Finish initial routing
    [driver.kicad_pcb, driver.sch]
2019-01-18 driver: initial DRC done
    [driver.kicad_pcb]
2019-01-19 driver: Fixup SWD header, swap driver outputs for VSW split, finish silk
    [driver.kicad_pcb, driver.sch]
2019-01-19 driver: Fatten a few power traces
    [driver.kicad_pcb]
2019-01-19 Fix up a couple of dimensions
    [driver.kicad_pcb]
2019-01-23 Fix R1 footprint
    0603 -> 1206
    [driver.kicad_pcb, driver.sch]
2019-01-29 Modify temp sensor to MSOP fp, add fan conn
    [driver.kicad_pcb, driver.sch]
2019-01-29 driver: Add mounting holes for RS485 adapter
    [driver.kicad_pcb, driver.sch]
2019-01-30 Fix lcd connector position
    [driver.kicad_pcb]
2019-01-30 Throw out a bunch, use a different microcontroller
    [driver.kicad_pcb, driver.sch]
2019-01-31 Small adjustments, fix silk
    [driver-B.Cu.gbr, driver-B.Mask.gbr, driver-B.Paste.gbr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]
2019-01-31 driver: Move traces away from board edge
    [driver-B.Cu.gbr, driver-B.Mask.gbr, driver-B.Paste.gbr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]
2019-01-31 driver: Add mounting holes for heatsink
    [driver-B.Cu.gbr, driver-B.Mask.gbr, driver-B.Paste.gbr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]
2019-01-31 driver: Add board revision, fix up mask
    [driver-B.Cu.gbr, driver-B.Mask.gbr, driver-B.Paste.gbr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]
2019-01-31 driver: Prettify heatsink mounting holes a bit
    [driver-B.Cu.gbr, driver-B.Mask.gbr, driver-B.Paste.gbr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]
2019-02-02 driver: fix a few misplaced vias, set grid origin, fix bottom mask
    [driver-B.Cu.gbr, driver-B.Mask.gbr, driver-B.Paste.gbr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]
2019-02-02 center: fix tape footprint polarity, vcc short, silk
    [center-B.Cu.gbr, center-B.Mask.gbr, center-B.Paste.gbr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]
2019-02-02 driver: add export w/ artwork
    [driver-B.Cu.gbr, driver-B.Mask.gbr, driver-B.Paste.gbr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]
2019-03-04 driver/fw: Beginnings of a firmware
    This code starts up and blinks a led. This means RCC, GPIO and SPI1 are working.
    [driver.sch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]
2019-03-04 driver/fw: Handle blink from systick
2019-03-04 driver/fw: timer-based tx ported
2019-03-04 driver/fw: Add missing startup and system file
2019-03-05 driver/fw: USART if working
2019-04-14 driver/fw: I2C LCD working
2019-04-14 driver/hw: add a bunch of todos
    [driver.sch]
2019-04-14 driver/fw: Temp sensor working modulo some brownout condition
    [i2c.h, main.c, mcp9801.c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]
2019-04-15 driver/fw: current sensor works
    [driver.sch]
2019-04-15 driver/fw: Add tiny printf
    [driver.sch]
2019-04-23 Fix up modulation and lcd transfer scheduling
    [lcd1602.c, main.c]
2019-04-23 driver: Fix temp sensor init in prototype hardware
    [main.c]
2019-04-23 driver: Make fw not short-circuit itself on startup
    [driver.sch]
2019-04-23 driver: Add ac bc framing and a bunch of comments
    [driver.sch]
2019-04-24 driver: Fix ALL the PCB issues in R3
    [bom_driver.ods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]
2019-04-25 driver: Finish R4 artwork and gerber export
    [driver-B_Cu.gbr, driver-B_Mask.gbr, driver-B_Paste.gbr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]
2019-05-12 Repo cleanup
    [circle_template.dxf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]
2019-05-12 Fixup receiver timeout setting, add some doc
    [8seg_protocol.c, adc.c]
2019-05-19 Add mounting structure simulation

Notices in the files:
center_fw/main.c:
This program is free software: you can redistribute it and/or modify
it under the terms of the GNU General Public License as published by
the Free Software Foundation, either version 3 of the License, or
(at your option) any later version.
